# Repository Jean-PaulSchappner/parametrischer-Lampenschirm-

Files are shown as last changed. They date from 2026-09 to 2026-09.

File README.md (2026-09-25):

# Lampenschirm Studio

Web-App zum Gestalten parametrischer Lampenschirme für den 3D-Druck: Geflecht, Strickmuster oder Korbstruktur auf einer frei einstellbaren oder aus einer STL gelernten Form, mit Sockel, Fassung oder LED-Panel und Diffusor. Dazu eine gleichwertige OpenSCAD-Fassung für den Parametric Model Maker von MakerWorld.

## Starten

`index.html` im Browser öffnen (Chrome, Edge oder Firefox). Eine Internetverbindung ist nötig, weil Three.js und die Schriften per CDN geladen werden. Eine Installation ist nicht nötig.

## Ordner

| Pfad | Inhalt |
|---|---|
| `index.html` | Die App (eine Datei, enthält auch die OpenSCAD-Vorlage für den Export) |
| `makerworld/lampenschirm.scad` | Parametrisches OpenSCAD-Modell, gleiches Ergebnis wie die App |
| `makerworld/BESCHREIBUNG.md`, `makerworld/bilder/` | Texte, Bilder und Schritte für die Veröffentlichung auf MakerWorld |
| `tests/pruefen.mjs` | Prüft Vorlagen, Passungen, Korrekturen, STL-Lernen und die OpenSCAD-Fassung |
| `werkzeuge/` | Hilfsskripte für die OpenSCAD-Vorlage |

## Was sich einstellen lässt

| Gruppe | Einstellungen |
|---|---|
| Grundform | Parametrisch oder aus einer hochgeladenen STL gelernt; Größe, Mischung mit der parametrischen Form, Glättung |
| Form | Höhe, Radius unten/oben, Wölbung mit Position, Wellen-Rillen oder gestapelte Kissen-Etagen (Tiefe, Anzahl, Prallheit), Kanten oben/unten abrunden (höchstens 35° Neigung) |
| Querschnitt & Drehung | Rund oder abgerundetes Drei- bis Achteck, Eckigkeit, Seitenverhältnis; Unter- und Oberkante einzeln drehen; zusätzliche Verdrehung (gleichmäßig, S-Kurve, hin und zurück oder als Falte mit Höhe und Breite) |
| Muster | Gekreuztes Geflecht (Leinwand, Köper 2/2, Köper 2/1, Webversatz, seitliche Wellen), Spirale, Strickmuster (Maschen, Reihenabstand, Zickzack, Wölbung, Fadenhöhe), Korbstruktur (Stäbe, Bänder, Versatz, einfach/doppelt), keins |
| Stabilität | Senkrechte Rippen, Zwischenringe, Höhe und Stärke der Ränder |
| Leuchtmittel | Speichen oben/unten im Schirm, Boden fest im Schirm oder im Sockel; Fassung E27/E14/GU10 (mit Kragen und Aussparungen), LED-Puck oder LED-Panel mit Einlasstiefe, Auflagekante und Passungsspiel; Diffusor als Platte oder Haube, bündig versenkt, Dichte über eine Wabenstruktur |
| Sockel | Höhe, Überstand, Wand, Deckel, Kabelschlitz, Einstecktiefe der Schirmlippe (1,6–25 mm) |
| Darstellung & Export | Farbe, Auflösung, Umdrehen für den Druck |

Vorlagen: Woven Light (Start), Woven Light · Panel 120×160, Woven Light · Mitte gedreht, Korb-Lampe, Korb · Panel 120×160 · Sockel, Strick-Lampe, Strick · Panel 120×160 · Sockel, Woven Light · Sockel getrennt, Panel 120×160 · Sockel getrennt, Mesh Tischlampe, Kissen-Stapel, Mesh mit LED-Panel, Mesh Kelch, Woven Mesh, Propeller, Diamant, Tulpe, Welle, Käfig, Kugel. „Zufall“ erzeugt Varianten mit druckbarem Überhang.

„Licht an“ zeigt die Lampe im dunklen Raum mit dem Schattenmuster an der Wand, „Zerlegt“ hebt den Schirm vom Sockel ab.

Die Einstellungen stehen in der Adresszeile („Link kopieren“) und lassen sich als JSON speichern und laden. Eine gelernte Form wird in der JSON-Datei mitgespeichert.

## Formen aus STL lernen

In der Gruppe „Grundform“ eine STL hochladen (Vase, Lampe, Flasche …) und die Hochachse wählen. Die App schneidet das Modell in 64 waagerechte Scheiben und misst in jeder Scheibe in 144 Richtungen den äußersten Punkt der Außenhaut. Richtungen ohne Treffer, etwa durch die Löcher eines Gitters, werden aus den Nachbarn ergänzt. Das Ergebnis ist ein Radiusfeld, das als Grundform dient:

- Alle Muster, Drehungen, Kantenrundungen, Wölbungen, Sockel, Fassungen, Panels und Diffusoren funktionieren darauf.
- „Mischung mit parametrischer Form“ blendet zwischen gelernter und eingestellter Form über und erzeugt so neue Formen.
- Die gelernten Formen bleiben im Browser gespeichert („Formbibliothek“) und lassen sich als Datei sichern und laden.

Geeignet sind Formen, die von der Mitte aus gesehen keine Hinterschneidungen haben (jede Richtung trifft die Außenhaut einmal). Innenteile wie Böden oder Fassungsringe stören nicht, es zählt der äußerste Punkt. Bei Gittermodellen liegt die gelernte Fläche auf der Außenseite der Stränge, also etwa 0,5 bis 1 mm außerhalb ihrer Mitte.

## OpenSCAD und MakerWorld

„OpenSCAD für MakerWorld exportieren“ schreibt den aktuellen Entwurf als `.scad`-Datei: alle Werte als Voreinstellungen der Regler, eine gelernte Form als Radiusfeld. Die Datei läuft ab OpenSCAD 2021.01 und im Parametric Model Maker von MakerWorld. Über den Regler `teil` entstehen Schirm, Sockel (kopfüber) oder Diffusor, `ansicht` zeigt alles zusammengebaut.

Die OpenSCAD-Fassung rechnet genau wie die App: Maße, Volumen und Dreieckszahl stimmen bei allen geprüften Vorlagen überein. Jedes Teil ist ein einzelnes Netz ohne Boolesche Vereinigung. Rechenzeit mit OpenSCAD 2021.01 bei Ausgabe als 3MF: Schirm mit 150 Strängen je Richtung 13 s, Sockel 1 s. Als Text-STL braucht OpenSCAD 2021 deutlich länger (rund 100 s für denselben Schirm).

Veröffentlichen: siehe `makerworld/BESCHREIBUNG.md`. Wurde `makerworld/lampenschirm.scad` geändert, danach `node werkzeuge/scad-einbetten.mjs` ausführen, damit der Export der App dieselbe Vorlage benutzt. `node werkzeuge/makerworld-paket.mjs "Vorlagenname"` setzt die Voreinstellungen der Datei auf eine Vorlage der App.

## Prüfen

```
node tests/pruefen.mjs
OPENSCAD="C:/Pfad/zu/openscad.com" node tests/pruefen.mjs
```

Geprüft werden: alle Vorlagen ohne Warnung und mit geschlossenen Teilen; die Passung von Panel, Puck, Diffusor und Schirmlippe im Netz nachgemessen; alle automatischen Korrekturen; das Lernen aus STL (Genauigkeit gegen die bekannte Form); mit gesetztem `OPENSCAD` zusätzlich der Vergleich App ↔ OpenSCAD für zehn Teile.

## Druckhinweise

- Export als binäre STL in Millimetern. Die Stränge durchdringen sich an den Kreuzungen; Bambu Studio, PrusaSlicer und Cura vereinen das beim Slicen.
- Keine Stützen nötig, solange die Anzeige grün ist. Neben jeder roten Warnung steht „Korrigieren“ (bei mehreren „Alles korrigieren“). Die Korrektur ändert nur die verursachenden Werte, so wenig wie nötig, und prüft danach, dass keine neue Warnung entsteht.
- Überhang: gemessen wird der Verlauf der Stränge ohne den Webversatz, Grenze etwa 55°. Beim Strickmuster zählt die Neigung von Reihe zu Reihe. Kantenrundungen sind auf 35° begrenzt, damit diagonale Stränge darauf druckbar bleiben.
- Webmuster gehen nur rundum auf, wenn die Strangzahl passt; die App rundet sie bei Bedarf auf (Leinwand gerade, Köper 2/2 Vielfaches von 4, Köper 2/1 Vielfaches von 3).
- Strickmuster: Nachbarreihen müssen sich mindestens 0,3 mm überlappen. Korbstruktur: zwischen den Stäben höchstens 15 mm freie Brücke.
- Sockel und Schirm sind getrennte Teile. Der Sockel wird kopfüber ausgegeben (Deckel auf dem Druckbett). Die Schirmlippe steckt mit 0,3 mm Spiel je Seite in der Nut.
- Panel- und Puckmaße als Nennmaß eintragen; der Einlass ist genau um das Passungsspiel größer (Standard 0,2 mm, auch an den Ecken), der Diffusor hat exakt das Nennmaß. Dreht man die Unterkante, drehen Leuchtmittel, Einlass und Diffusor mit.
- Diffusor in Weiß oder Natur (PLA/PETG), 0,6–1,2 mm Grundschicht, 100 % Füllung.
- Das Lochmaß für die Fassung mit einem kleinen Probedruck prüfen; Fassungsringe unterscheiden sich je nach Hersteller.
- Nur LED-Leuchtmittel verwenden. PLA wird ab etwa 55 °C weich.

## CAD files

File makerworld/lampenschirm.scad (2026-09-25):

// Parametrischer Lampenschirm – Geflecht, Strick, Korb, gelernte Formen
// Gegenstück zur Web-App „Lampenschirm Studio“ (index.html). Alle Maße in mm, Winkel in Grad.
// Jedes Teil wird als ein einziges Netz ausgegeben (keine Boolesche Vereinigung), damit es schnell rechnet.
// Die Stränge durchdringen sich an den Kreuzungen; Bambu Studio, PrusaSlicer und Cura vereinen das beim Slicen.

/* [Teil] */
// Welches Teil erzeugt wird. „Zusammengebaut“ ist nur zum Ansehen, nicht zum Drucken.
teil = "schirm"; // [schirm:Schirm, sockel:Sockel (kopfüber zum Drucken), diffusor:Diffusor, ansicht:Zusammengebaut (Ansicht)]

/* [Grundform] */
// Parametrisch oder die aus einer STL gelernte Form (nur verfügbar, wenn aus der App exportiert)
grundform = "param"; // [param:Parametrisch, stl:Gelernte Form]
// Größe der gelernten Form in Prozent
formSkala = 100; // [30:1:300]
// Mischung der gelernten mit der parametrischen Form in Prozent
formMix = 0; // [0:1:100]

/* [Form] */
hoehe = 240; // [60:1:400]
radiusUnten = 80; // [20:1:200]
radiusOben = 80; // [20:1:200]
// Wölbung nach außen (positiv) oder innen (negativ)
bauch = -3; // [-80:1:80]
bauchPos = 0.4; // [0.1:0.01:0.9]
rillenForm = "welle"; // [welle:Wellen-Rillen, kissen:Kissen-Etagen]
rillenAmp = 0; // [0:0.5:30]
rillenAnzahl = 4; // [1:1:12]
prallheit = 0.55; // [0:0.01:1]
kanteUnten = 3; // [0:0.5:30]
kanteOben = 10; // [0:0.5:30]

/* [Querschnitt und Drehung] */
querschnitt = 4; // [0:Rund, 3:Dreieck, 4:Viereck, 5:Fünfeck, 6:Sechseck, 8:Achteck]
eckigkeit = 4.2; // [2.2:0.1:16]
// Tiefe im Verhältnis zur Breite
seitenVerhaeltnis = 1; // [0.5:0.01:2]
drehUnten = 0; // [-180:1:180]
drehOben = 0; // [-180:1:180]
// Zusätzliche Verdrehung über die Höhe
verdrehung = 30; // [-180:1:180]
verdrehVerlauf = "lokal"; // [linear:Gleichmäßig, s:S-Kurve, welle:Hin und zurück, lokal:Falte]
verdrehMitte = 0.38; // [0.1:0.01:0.9]
verdrehBreite = 0.2; // [0.05:0.01:0.6]

/* [Muster] */
muster = "geflecht"; // [geflecht:Geflecht gekreuzt, rechts:Spirale rechts, links:Spirale links, strick:Strickmuster, korb:Korbstruktur, keine:Kein Geflecht]
// Geflecht: Stränge je Richtung
straenge = 150; // [3:1:220]
// Geflecht: Umdrehungen der Stränge über die Höhe
drehung = 0.36; // [0:0.01:2.5]
strangBreite = 2; // [0.8:0.1:10]
strangTiefe = 1.2; // [0.6:0.1:6]
webart = "leinwand"; // [leinwand:Leinwand, koeper22:Köper 2/2, koeper21:Köper 2/1]
webTiefe = 0.45; // [0:0.05:3]
wellenAmp = 0; // [0:0.5:20]
wellenFreq = 4; // [1:1:16]
maschen = 110; // [20:1:400]
strickReihe = 2.6; // [1.5:0.1:8]
strickHub = 0.7; // [0:0.05:3]
strickTiefe = 0.9; // [0:0.05:3]
strickHoehe = 2; // [0.8:0.1:6]
korbStaebe = 40; // [8:2:160]
korbStabBreite = 2.4; // [1:0.1:8]
korbStabDicke = 2.2; // [1:0.1:6]
korbReihe = 7; // [2:0.1:20]
korbBand = 5; // [1:0.1:18]
korbVersatz = 1; // [0:0.05:3]
korbFolge = "einfach"; // [einfach:Einfach, doppelt:Doppelt]

/* [Stabilität] */
rippen = 0; // [0:1:48]
zwischenRinge = 0; // [0:1:12]
randHoehe = 2.5; // [0:0.5:20]
randDicke = 2.2; // [1:0.1:10]

/* [Leuchtmittel] */
fassung = true;
fassungPos = "sockel"; // [oben:Speichen oben (Pendelleuchte), unten:Speichen unten, boden:Boden fest im Schirm, sockel:Im Sockel]
einsatz = "fassung"; // [fassung:Lampenfassung, puck:LED-Puck rund, panel:LED-Panel rechteckig]
lochD = 42; // [15:0.5:80]
fassRing = 8; // [2:0.5:20]
speichen = 4; // [2:1:12]
speichenBreite = 5; // [2:0.5:15]
speichenHoehe = 4; // [1.5:0.5:12]
bodenDicke = 2.4; // [1.2:0.1:6]
kragen = 6; // [0:0.5:20]
nasen = 4; // [0:1:6]
puckD = 70; // [30:0.5:180]
panelB = 120; // [20:0.5:240]
panelL = 160; // [20:0.5:240]
panelEcke = 3; // [0:0.5:30]
// Dicke von Panel bzw. Puck
einsatzTiefe = 8; // [0:0.5:25]
falz = 3; // [1:0.5:12]
// Passungsspiel je Seite zwischen Leuchtmittel und Einlass
spiel = 0.2; // [0:0.05:1]

/* [Diffusor] */
diffusor = true;
diffusorForm = "flach"; // [flach:Flache Platte, haube:Haube]
diffusorVersenkt = true;
diffusorDicke = 0.8; // [0.4:0.1:3]
diffusorDichte = 0; // [0:5:100]
diffusorNoppe = 0.6; // [0.2:0.1:2]
diffusorRaster = 3; // [1.5:0.5:8]
diffusorHoehe = 20; // [3:0.5:80]
diffusorWand = 1.2; // [0.8:0.1:3]

/* [Sockel] */
sockel = true;
sockelHoehe = 60; // [20:1:150]
sockelUeberstand = 2; // [0:0.5:20]
sockelWand = 2.4; // [1.2:0.1:6]
sockelDeck = 3.2; // [2.5:0.1:6]
kabelD = 8; // [0:0.5:16]
lippe = 10; // [1.6:0.5:25]

/* [Qualität] */
// Mehr = feiner, aber langsamer
aufloesung = 140; // [40:10:400]
// Schirm mit Speichen oben zum Drucken umdrehen
druckUmdrehen = true;

/* [Hidden] */
formName = "";
formFeld = [];

/* ===================================================================== Hilfsfunktionen */
function clamp(x, a, b) = min(b, max(a, x));
function sq(x) = x * x;
function nrm(v) = let(l = norm(v)) l > 0 ? v / l : v;
function lerp(a, b, f) = a + (b - a) * f;
function tanh_(x) = let(e = exp(2 * x)) (e - 1) / (e + 1);
function wrap(a) = a - 360 * floor((a + 180) / 360);
function rot2(v, a) = [v[0] * cos(a) - v[1] * sin(a), v[0] * sin(a) + v[1] * cos(a)];
function qsort(v) = len(v) <= 1 ? v : let(p = v[floor(len(v) / 2)])
  concat(qsort([for (x = v) if (x < p) x]), [for (x = v) if (x == p) x], qsort([for (x = v) if (x > p) x]));
function merge(ms) = let(n = len(ms), offs = [for (i = 0, o = 0; i < n; o = o + len(ms[i][0]), i = i + 1) o])
  [[for (m = ms) each m[0]], [for (i = [0:1:n - 1]) for (f = ms[i][1]) [for (v = f) v + offs[i]]]];
EMPTY = [[], []];

/* ===================================================================== Profil */
H = hoehe;
res = aufloesung;
function edgeIn(z, r) = r <= 0 ? 0 : let(h = r * sin(35)) z >= h ? 0 : r - sqrt(r * r - sq(h - z));
function bump(t) = t < bauchPos ? sq(sin(90 * t / bauchPos)) : sq(sin(90 * (1 - t) / (1 - bauchPos)));
function rillen(t) = rillenForm == "kissen"
  ? rillenAmp * (pow(abs(sin(180 * rillenAnzahl * t)), 1 - 0.85 * prallheit) - 1)
  : rillenAmp * sin(360 * rillenAnzahl * t);
function modR(t) = bauch * bump(t) + rillen(t) - edgeIn(t * H, kanteUnten) - edgeIn((1 - t) * H, kanteOben);
function Rp(t) = max(8, radiusUnten + (radiusOben - radiusUnten) * t + modR(t));

/* ===================================================================== Querschnitt (Superformel) */
function rho(phi) = querschnitt == 0 ? 1
  : pow(pow(abs(cos(querschnitt * phi / 4)), eckigkeit) + pow(abs(sin(querschnitt * phi / 4)), eckigkeit), -1 / eckigkeit);
function loc(phi) = rho(phi) * [cos(phi), seitenVerhaeltnis * sin(phi)];
KA = 1440;
ARC = [for (k = 0, acc = 0; k <= KA; acc = acc + norm(loc(360 * (k + 1) / KA) - loc(360 * k / KA)), k = k + 1) acc];
TOTAL = ARC[KA];
ARCTAB = [for (k = [0:KA]) [ARC[k] / TOTAL, 360 * k / KA]];
KS = 1024;
// Winkel zu gleichmäßig verteilter Bogenlänge, damit die Stränge auch an den Ecken gleich dicht liegen
PHITAB = [for (k = [0:KS]) lookup(k / KS, ARCTAB)];
// k begrenzen: bei knapp negativem s rundet s - floor(s) auf 1, dann läge k hinter dem Tabellenende
function phiOfS(s) = let(u = (s - floor(s)) * KS, k = min(KS - 1, floor(u)), f = u - k) PHITAB[k] + (PHITAB[k + 1] - PHITAB[k]) * f;
function radiusDirP(b) = norm(loc(atan2(sin(b) / seitenVerhaeltnis, cos(b))));

/* ===================================================================== Gelernte Form */
FT = len(formFeld);
FA = FT > 0 ? len(formFeld[0]) : 0;
LEARN = grundform == "stl" && FT > 1;
function F(phi, t) = let(
    u = (phi / 360 - floor(phi / 360)) * FA, j0 = floor(u) % FA, j1 = (j0 + 1) % FA, fu = u - floor(u),
    v = clamp(t * FT - 0.5, 0, FT - 1), i0 = floor(v), i1 = min(FT - 1, i0 + 1), fv = v - i0,
    a = lerp(formFeld[i0][j0], formFeld[i0][j1], fu), b = lerp(formFeld[i1][j0], formFeld[i1][j1], fu))
  lerp(a, b, fv);
function rPolar(phi, t) = let(rl = formSkala / 100 * F(phi, t) + modR(t)) max(4, rl + (Rp(t) * radiusDirP(phi) - rl) * formMix / 100);

/* ===================================================================== Drehung */
function twf(t) =
  verdrehVerlauf == "s" ? (1 - cos(180 * t)) / 2 :
  verdrehVerlauf == "welle" ? sin(180 * t) :
  verdrehVerlauf == "lokal" ? let(g0 = tanh_(-verdrehMitte / verdrehBreite), g1 = tanh_((1 - verdrehMitte) / verdrehBreite))
    (tanh_((t - verdrehMitte) / verdrehBreite) - g0) / (g1 - g0) : t;
function ends(t) = verdrehVerlauf == "welle" ? (1 - cos(180 * t)) / 2 : twf(t);
function tw(t) = drehUnten + (drehOben - drehUnten) * ends(t) + verdrehung * twf(t);
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

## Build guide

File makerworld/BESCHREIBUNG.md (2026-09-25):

# MakerWorld-Paket: Parametrischer Lampenschirm

Dieser Ordner enthält alles, was für die Veröffentlichung als parametrisches Modell (OpenSCAD) auf MakerWorld gebraucht wird.

| Datei | Zweck |
|---|---|
| `lampenschirm.scad` | Das parametrische Modell für den MakerWorld Parametric Model Maker. Voreinstellung: Geflecht-Tischlampe mit getrenntem Sockel und E27-Fassung. |
| `bilder/01…06_*.png` | Titel- und Galeriebilder (Renderings aus der App, 1600 × 1200) |
| `BESCHREIBUNG.md` | Diese Datei: Texte für die Modellseite und die Schritte zum Hochladen |

## So wird veröffentlicht

1. Auf makerworld.com anmelden, oben auf „Upload“ und dann „Parametric Model“ (OpenSCAD) wählen.
2. `lampenschirm.scad` hochladen. MakerWorld liest die Regler aus den Kommentaren der Datei; im Vorschaufenster prüfen, dass Schirm, Sockel und Diffusor über den Regler „teil“ erzeugt werden.
3. Die Bilder aus `bilder/` hochladen, `02_woven_light_licht.png` oder `01_woven_light.png` als Titelbild. Sobald eine echte Lampe gedruckt ist, Fotos davon ergänzen: Renderings allein wirken weniger glaubwürdig.
4. Titel, Kurzbeschreibung und Beschreibung aus dem Abschnitt unten übernehmen.
5. Lizenz wählen (Vorschlag: CC BY-NC-SA 4.0 für Privatnutzung mit Namensnennung, oder CC BY 4.0, wenn auch kommerzielle Nutzung erlaubt sein soll).
6. Die Geflecht-Variante ist nach Fotos eines anderen MakerWorld-Modells nachgebaut. Den ursprünglichen Designer in der Beschreibung als Inspiration nennen und prüfen, ob MakerWorld das Modell als Remix verknüpft haben möchte.
7. Veröffentlichen.

Eigene Varianten: In der App (`index.html`) gestalten und mit „OpenSCAD für MakerWorld exportieren“ eine neue `.scad` erzeugen. Deren Voreinstellungen entsprechen dann genau dem Entwurf, auch mit einer aus einer STL gelernten Grundform.

Rechenzeit (gemessen mit OpenSCAD 2021.01 auf einem Windows-PC, Ausgabe als 3MF): Schirm mit 150 Strängen je Richtung 13 s, Sockel 1 s, alles zusammengebaut 13 s. Die Ausgabe als Text-STL ist in OpenSCAD 2021 deutlich langsamer (rund 100 s für den Schirm); MakerWorld erzeugt 3MF.

---

## Texte für die Modellseite

### Titel
Parametrischer Lampenschirm – Geflecht, Strick & Korb (mit Sockel für E27, LED-Puck oder LED-Panel)

### Kurzbeschreibung
Gestalte deinen eigenen Lampenschirm: Form, Querschnitt, Drehung und Muster (gekreuztes Geflecht, Strickmuster oder Korbstruktur) frei einstellen. Mit passendem Sockel für E27/E14/GU10, LED-Puck oder rechteckiges LED-Panel und bündigem Diffusor. Druckt ohne Stützen.

### Beschreibung (Deutsch)

Ein parametrischer Tischlampen-Schirm aus einzelnen Strängen, die sich beim Druck zu einem feinen Geflecht verbinden. Alles lässt sich über die Regler einstellen:

**Form**
- Höhe, Radius unten und oben, Wölbung, Wellen-Rillen oder gestapelte Kissen-Etagen
- Querschnitt rund oder als abgerundetes Drei- bis Achteck, Eckigkeit, Seitenverhältnis
- Unter- und Oberkante einzeln drehen, zusätzliche Verdrehung, auch als Falte in einer Zone

**Muster**
- Gekreuztes Geflecht (Leinwand oder Köper) mit Über-/Unter-Versatz
- Horizontales Strickmuster
- Korbstruktur mit Stäben und Flechtbändern
- Spirale oder senkrechte Rippen

**Licht**
- Sockel als eigenes Teil mit Kabelschlitz; der Schirm steckt mit einer Lippe in einer Nut
- Lampenfassung E27/E14/GU10 mit Aussparungen im Loch, runder LED-Puck oder rechteckiges LED-Panel (z. B. 120 × 160 mm)
- Einlass mit einstellbarem Passungsspiel und Auflagekante
- Diffusor als flache Platte oder Haube, bündig versenkt, Dichte über eine Wabenstruktur einstellbar

**Drucken**
- Teil über den Regler „teil“ wählen: Schirm, Sockel (kommt kopfüber, Deckel auf dem Druckbett) oder Diffusor
- Keine Stützen nötig; die Stränge sind höchstens etwa 55° geneigt
- Empfehlung: 0,4-mm-Düse, 0,2-mm-Schichten, Schirm eher langsam (z. B. 60–80 mm/s Außenwand)
- Diffusor in Weiß oder Natur (PLA/PETG), 100 % Füllung
- Nur LED-Leuchtmittel verwenden; PLA wird ab etwa 55 °C weich

**Maße prüfen**
Panel- und Puckmaße als Nennmaß eintragen, das Spiel (Standard 0,2 mm je Seite) kommt automatisch dazu. Das Lochmaß der Fassung am besten mit einem kleinen Probedruck prüfen.

Erstellt mit „Lampenschirm Studio“, einer Web-App mit 3D-Vorschau, Druckbarkeitsprüfung mit automatischer Korrektur und der Möglichkeit, Grundformen aus eigenen STL-Dateien zu lernen.

### Description (English)

A parametric table-lamp shade made of individual strands that fuse into a fine woven mesh when printed. Everything is adjustable:

- **Shape:** height, bottom/top radius, bulge, ripples or stacked cushion tiers; round or rounded 3- to 8-sided cross-section, aspect ratio; rotate top and bottom edge independently, extra twist or a fold in one zone.
- **Patterns:** crossed weave (plain or twill) with over/under offset, horizontal knit, basket weave with stakes and weavers, spirals or vertical ribs.
- **Light:** separate base with cable slot, the shade plugs in with a lip; E27/E14/GU10 socket, round LED puck or rectangular LED panel (e.g. 120 × 160 mm) with adjustable clearance; flat or hood diffuser, sunk flush, density adjustable via a honeycomb structure.
- **Printing:** choose the part with the "teil" setting (shade, base printed upside down, diffuser). No supports needed. 0.4 mm nozzle, 0.2 mm layers. Diffuser in white or natural at 100 % infill. Use LED bulbs only.

### Tags
Lampenschirm, lampshade, parametric, OpenSCAD, woven, mesh, knit, basket, LED panel, E27, table lamp, Tischlampe, Geflecht

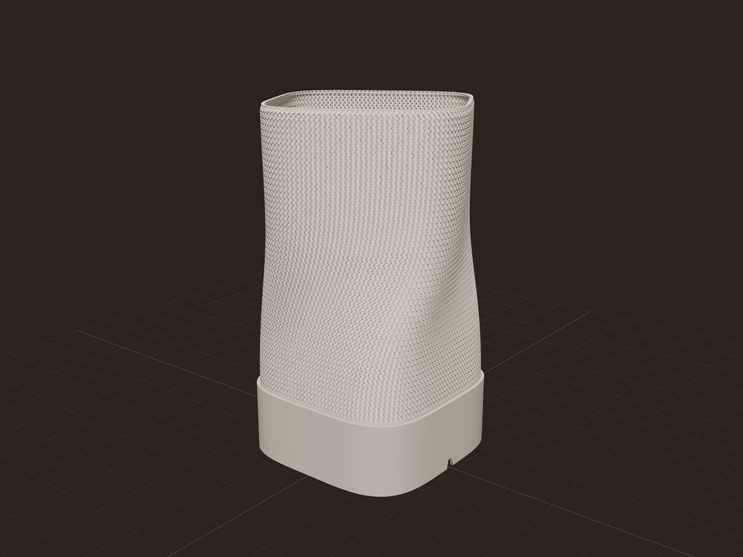
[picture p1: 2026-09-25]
makerworld/bilder/01_woven_light.png

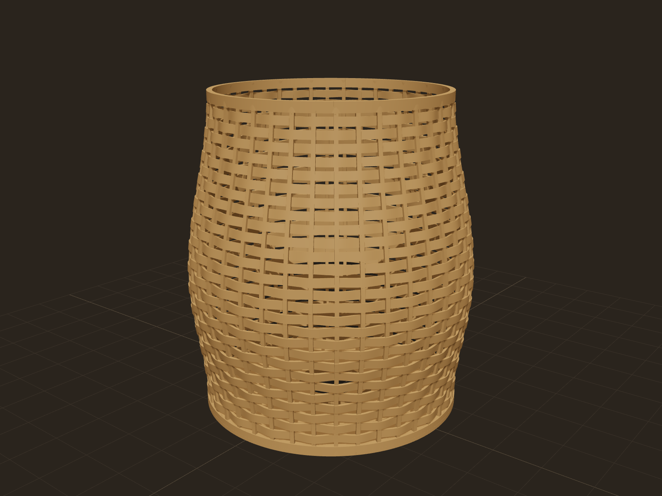
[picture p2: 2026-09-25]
makerworld/bilder/04_korbstruktur.png

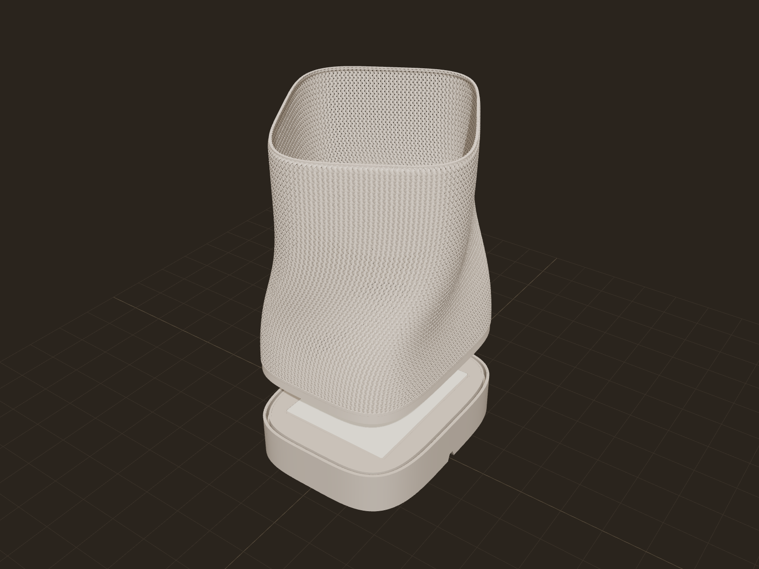
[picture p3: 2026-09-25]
makerworld/bilder/06_panel_sockel_zerlegt.png

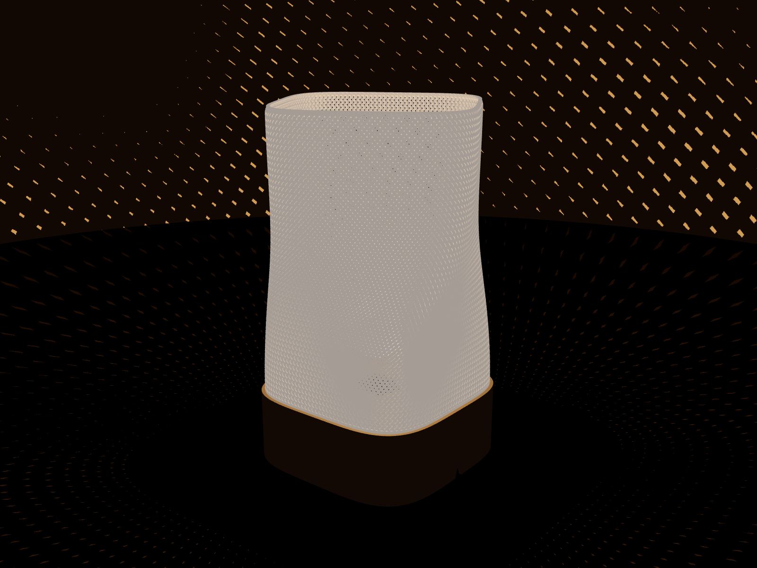
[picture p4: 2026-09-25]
makerworld/bilder/02_woven_light_licht.png

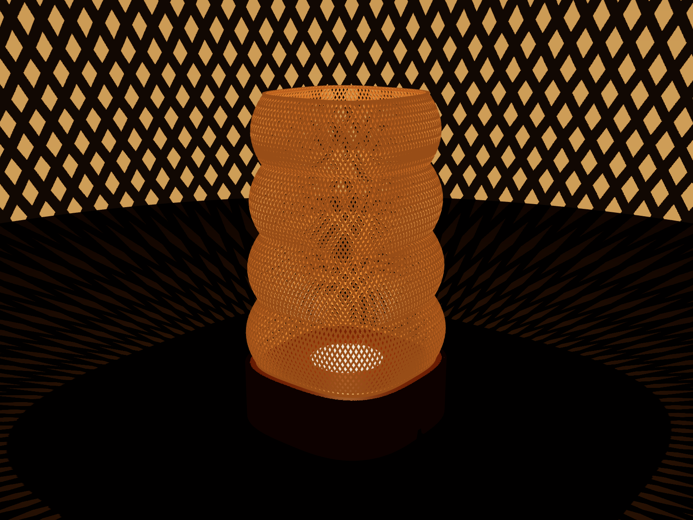
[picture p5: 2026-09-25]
makerworld/bilder/05_kissen_licht.png

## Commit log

2026-09-25 neue Lampenschirme
    [lampenschirm.scad]
2026-10-19 Prüfungen ohne Handarbeit, robustere Neuberechnung, MakerWorld-Danksagung
    - tests/pruefen.mjs findet OpenSCAD selbst (Umgebungsvariable, .openscad/, Standardinstallation, PATH)
    - npm-Skripte: start (lokaler Webserver), pruefen, openscad-holen, scad-einbetten, makerworld-paket
    - Neuberechnung per Timer statt requestAnimationFrame, damit Änderungen auch im Hintergrund-Tab greifen
    - MakerWorld-Beschreibung nennt das Original-Modell als Inspiration (Name des Designers noch eintragen)
2026-10-19 Wandspot mit echter Korbstruktur aus Volumen-Streben
    Neuer Lampentyp „Wandspot“ in der bestehenden Pipeline: Wandhalter (Platte mit
    Senklöchern, hohler Arm als Kabelkanal mit Knick, Zapfen) und Spotkopf
    (zylindrisch/konisch, Buchse, Frontöffnung, Frontring). Korbstruktur aus
    geschlossenen Streben mit Rechteckquerschnitt in fünf Strukturtypen mit
    echter Über/Unter-Lage. Netzprüfung der exportierten STL in der App,
    Warnungen mit Korrektur, sechs Vorlagen.
    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
